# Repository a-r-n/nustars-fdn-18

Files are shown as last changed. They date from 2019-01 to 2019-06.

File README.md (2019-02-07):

# NUSTARS Foundation 2018/19
For remote telemetry and data processing.

## Avionics
Language(s): C++  
Board: Feather M0  
Sensors:  
- BNO055  
- BMP280  
- Adafruit Ultimate GPS  
- ADXL377
Radio: LoRa RFM95W @915MHz
Commercial Altimeters: Raven 4

An ADS is controlled by interpreting signals from the commercial altimeters. General telemetry information is read from custom avionics suite, and is packaged and sent to ground station (as well as being saved to flash). At some point TBD, data will be retransmitted from flash (in the likely event of loss during the flight).

## Ground display and processing
Language(s): Python  
Radio: Feather M0 w/ LoRa RFM95W

The ground station is responsible for interpreting and displaying both real-time and asynchronous data from the avionics package.
Further information TBD

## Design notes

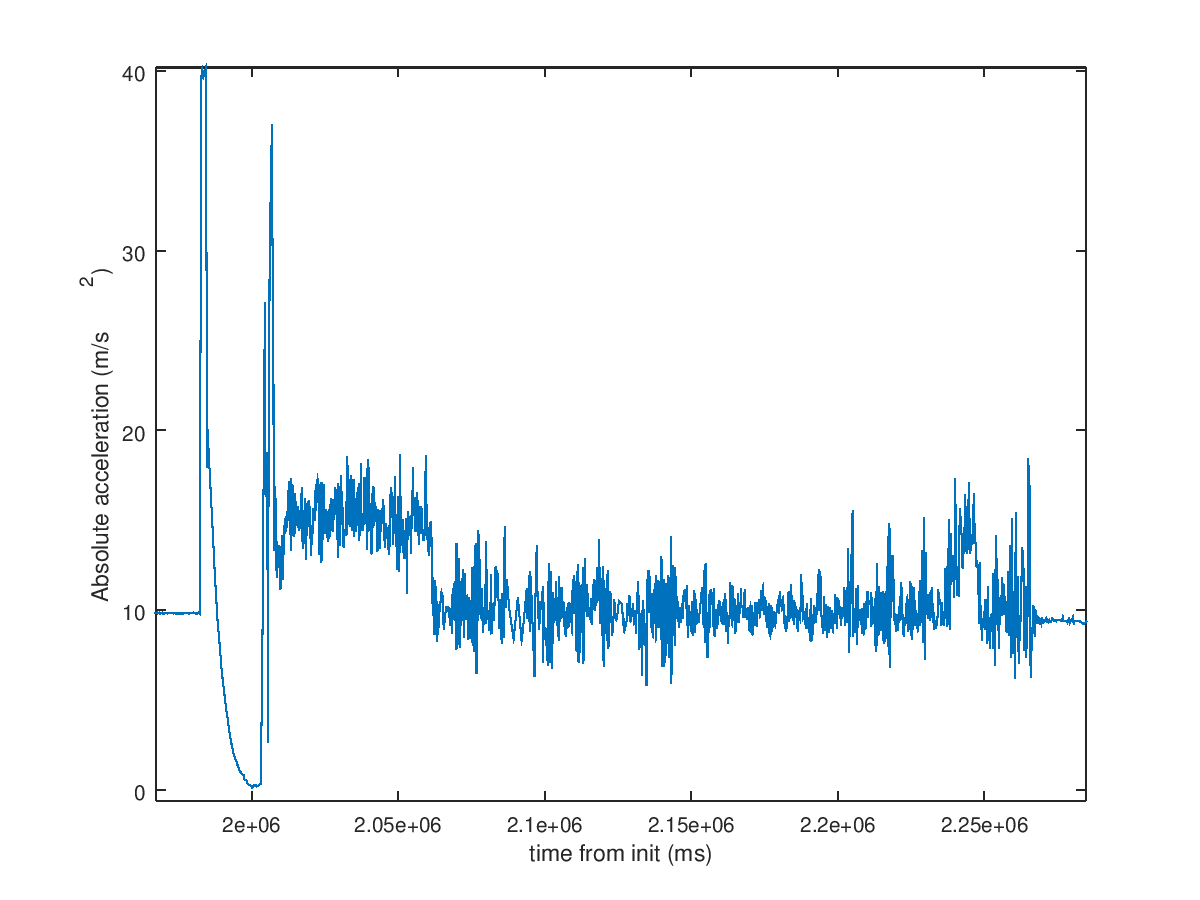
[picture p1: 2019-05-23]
matlab_parser/acc.png

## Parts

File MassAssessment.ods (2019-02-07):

Item | Mass (g) | Quantity | Subcost
M0 Exp | 4.7 | 1 | 4.7
LoRa | 4.6 | 1 | 4.6
GPS | 8.5 | 1 | 8.5
ADXL | 1.27 | 1 | 1.27
BNO | 3 | 1 | 3
BMP | 1.3 | 1 | 1.3
JST | 0.1 | 7 | 0.7
125x45 | 22.2 | 1 | 22.2
PerchRaven | 25 | 2 | 50
CylBats | 46 | 2 | 92
TOTAL |  |  | 188.27

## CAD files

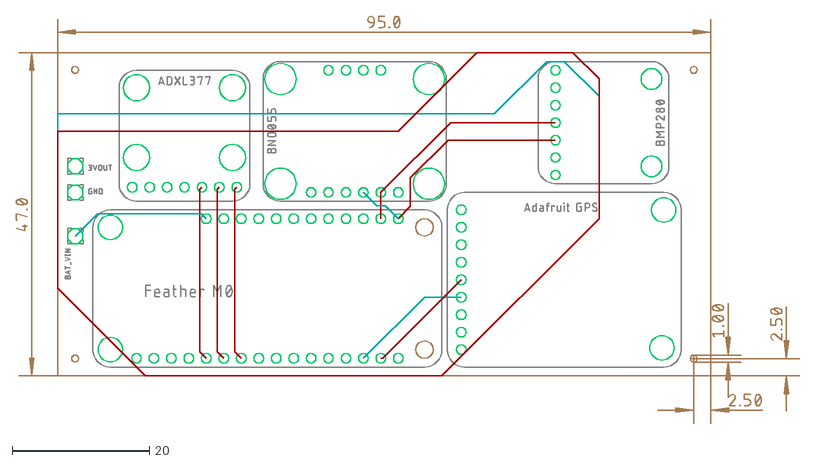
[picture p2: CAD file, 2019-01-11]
eagle/projects/NUSTARS18/Mainboard.dxf
114.0 x 59.2

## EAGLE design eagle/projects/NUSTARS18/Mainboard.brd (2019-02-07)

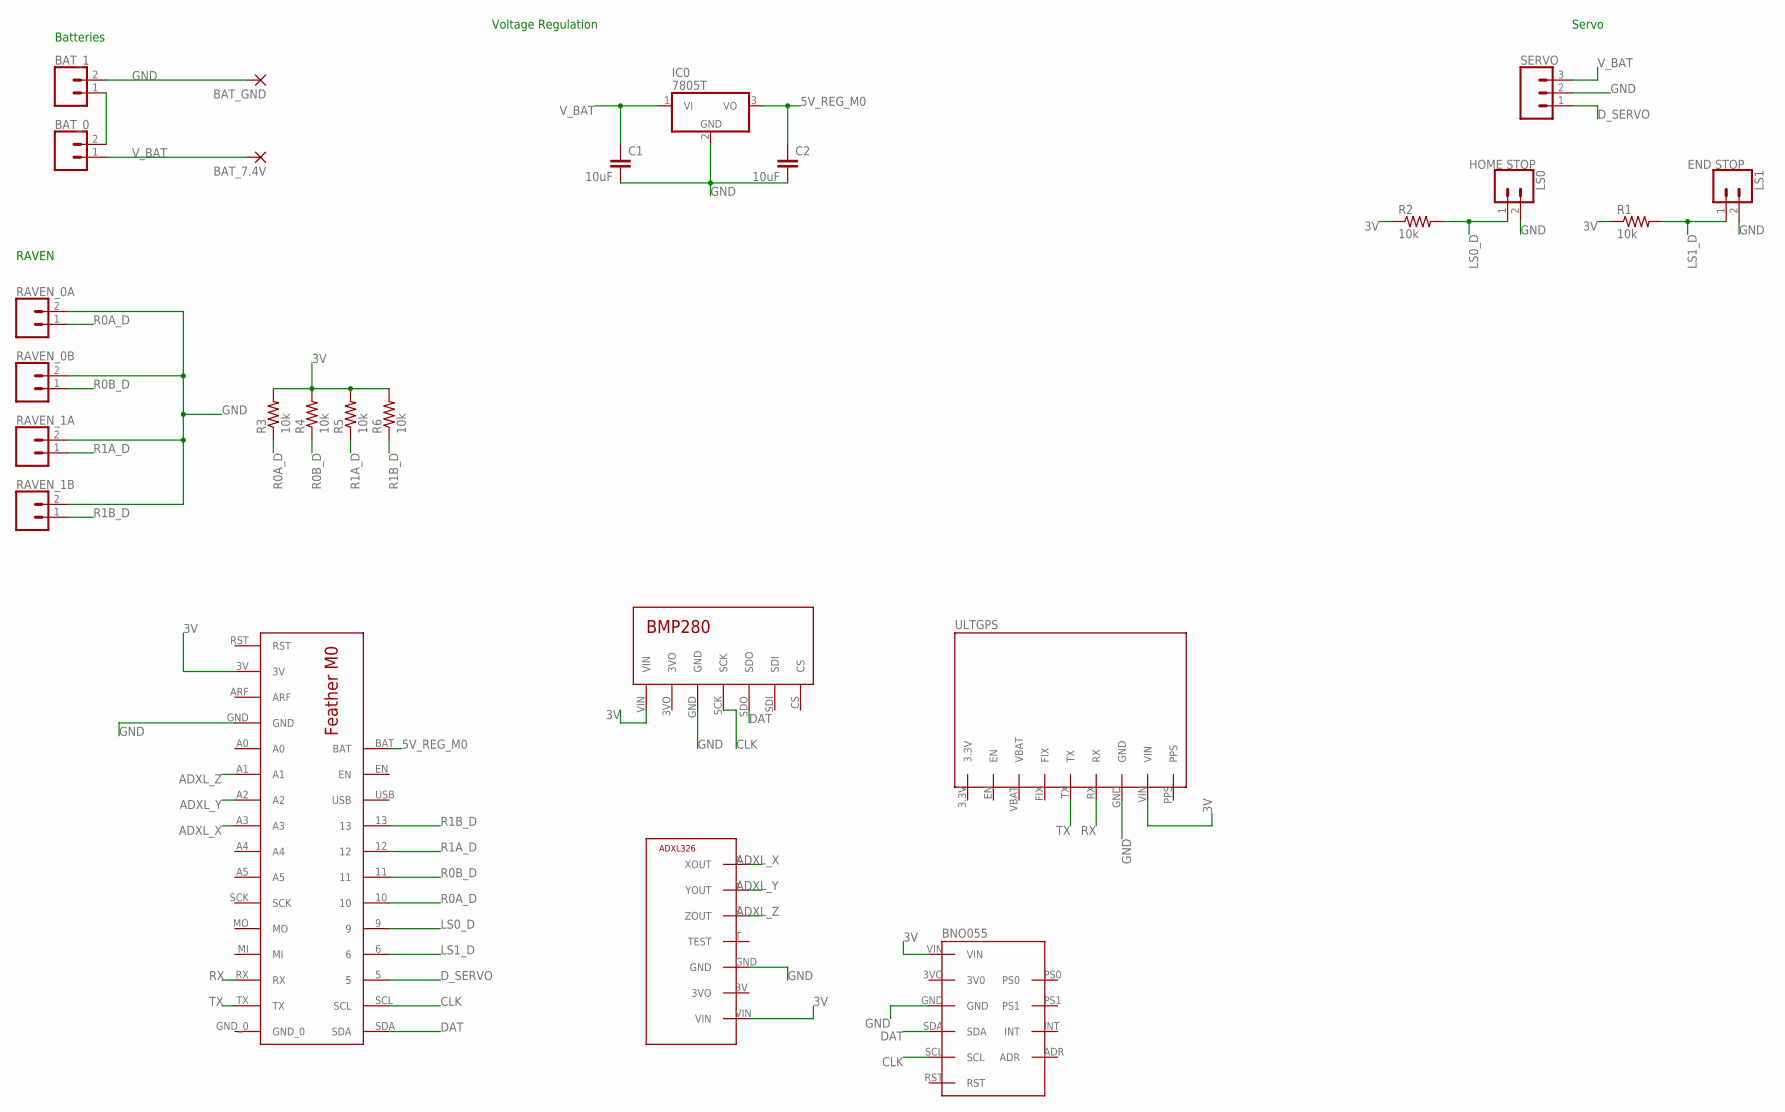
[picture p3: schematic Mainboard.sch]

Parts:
BAT_0, BAT_1: CONN_02JST-PTH-2; JST-2-PTH
BAT_7.4V: 3,81/1,4
BAT_GND: 3,81/1,4
C1, C2: 10uF; C2.5-3
IC0: 7805T; TO220H
LS0: HOME STOP; JST-2-PTH
LS1: END STOP; JST-2-PTH
R1, R2, R3, R4, R5, R6: 10k; 0207/10
RAVEN_0A, RAVEN_0B, RAVEN_1A, RAVEN_1B: CONN_02JST-PTH-2; JST-2-PTH
SERVO: CONN_03JST-PTH; JST-3-PTH
U$1: M0
U$2: BMP
U$3: ADXL377
U$4: ULTGPS
U$5: BNO055

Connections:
3V: R1.1, R2.1, R3.2, R4.2, R5.2, R6.2, U$1.3V, U$2.VIN, U$3.VIN, U$4.VIN, U$5.VIN
5V_REG_M0: C2.1, IC0.3 (VO), U$1.BAT
ADXL_X: U$1.A3, U$3.X (XOUT)
ADXL_Y: U$1.A2, U$3.Y (YOUT)
ADXL_Z: U$1.A1, U$3.Z (ZOUT)
B_INT: BAT_0.2, BAT_1.1
CLK: U$1.SCL, U$2.SCK, U$5.SCL
DAT: U$1.SDA, U$2.SDO, U$5.SDA
D_SERVO: SERVO.1, U$1.5
GND: BAT_1.2, BAT_GND.1, C1.2, C2.2, IC0.2 (GND), LS0.2, LS1.2, RAVEN_0A.2, RAVEN_0B.2, RAVEN_1A.2, RAVEN_1B.2, SERVO.2, U$1.GND, U$2.GND, U$3.GND, U$4.GND, U$5.GND
LS0_D: LS0.1, R2.2, U$1.9
LS1_D: LS1.1, R1.2, U$1.6
R0A_D: R3.1, RAVEN_0A.1, U$1.10
R0B_D: R4.1, RAVEN_0B.1, U$1.11
R1A_D: R5.1, RAVEN_1A.1, U$1.12
R1B_D: R6.1, RAVEN_1B.1, U$1.13
RX: U$1.RX, U$4.RX
TX: U$1.TX, U$4.TX
V_BAT: BAT_0.1, BAT_7.4V.1, C1.1, IC0.1 (VI), SERVO.3

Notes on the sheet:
Batteries
Voltage Regulation
Servo
RAVEN

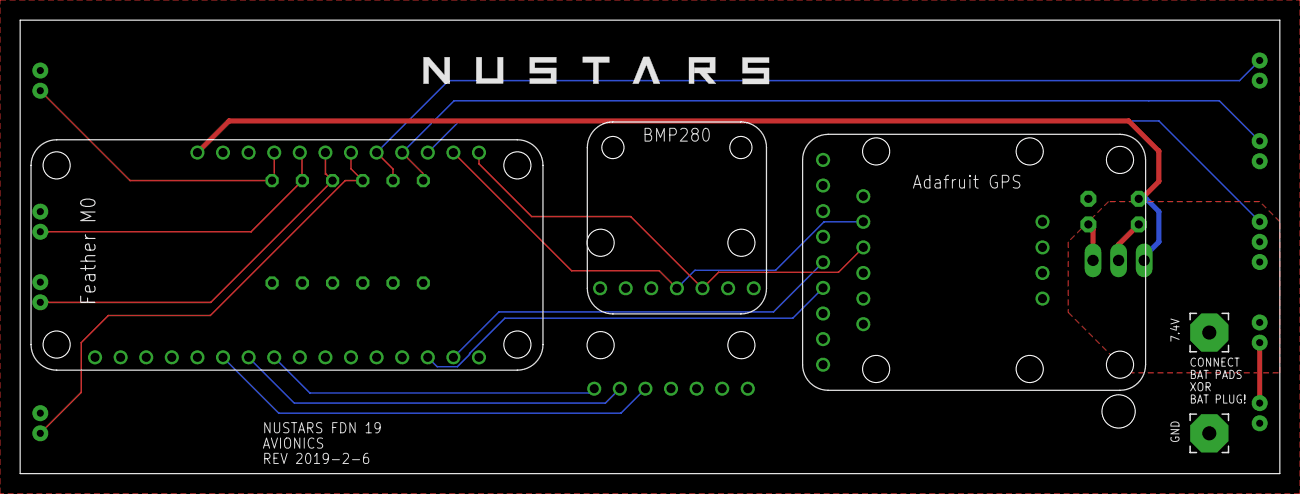
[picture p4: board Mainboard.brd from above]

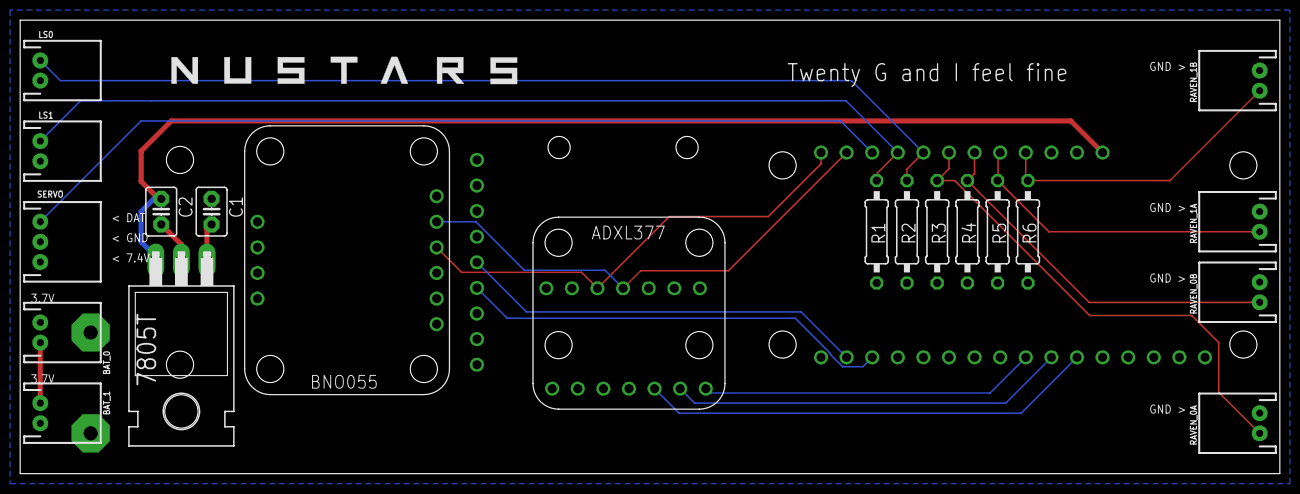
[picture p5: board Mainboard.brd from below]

Board: 2 copper layers, 125.0 x 45.0 mm, 25 parts (20 on the bottom side), 19 nets.

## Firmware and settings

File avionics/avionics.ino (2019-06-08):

#include "radio.h"
#include "sensors.h"
#include <Adafruit_NeoPixel.h>
#include <Adafruit_SPIFlash.h>
#include <Adafruit_SPIFlash_FatFs.h>
#include <SPI.h>
#include <Scheduler.h>
#include <Servo.h>
#include <Adafruit_GPS.h>
#include <Wire.h>

// FLASH DEFS TEMPORARY NO TIME

#define FLASH_TYPE                                                             \
  SPIFLASHTYPE_W25Q16BV // Flash chip type.
// If you change this be
// sure to change the fatfs
// object type below to match.

#if (SPI_INTERFACES_COUNT == 1)
#define FLASH_SS SS        // Flash chip SS pin.
#define FLASH_SPI_PORT SPI // What SPI port is Flash on?
#else
#define FLASH_SS SS1        // Flash chip SS pin.
#define FLASH_SPI_PORT SPI1 // What SPI port is Flash on?
#endif

// defining raven pins
#define R0A 10
#define R0B 11
#define R1A 12
#define R1B 13

// what's the name of the hardware serial port?
#define GPSSerial Serial1

// Connect to the GPS on the hardware port
Adafruit_GPS GPS(&GPSSerial);
#define GPSECHO false

#define PACKET_SIZE                                                            \
  70 // this is for optimization and ease of programming reasons... must be
// updated :(
#define WRITE_BUFFER_SIZE (2048 / PACKET_SIZE) * PACKET_SIZE

// setting debug stuff
#define DEBUG false
int divisor = 3;

// suspecting a race condition in the compiler or something else insane because
// this has to be moved sometimes for it to compile :O
union fusion_t {
  float f;
  int i;
  long l;
  uint8_t b[sizeof(long)];
};

// VERY TEMPORARY MEMORY CHECKING THING
#ifdef __arm__
// should use uinstd.h to define sbrk but Due causes a conflict
extern "C" char *sbrk(int incr);
#else  // __ARM__
extern char *__brkval;
#endif // __arm__

int freeMemory() {
  char top;
#ifdef __arm__
  return &top - reinterpret_cast<char *>(sbrk(0));
#elif defined(CORE_TEENSY) || (ARDUINO > 103 && ARDUINO != 151)
  return &top - __brkval;
#else  // __arm__
  return __brkval ? &top - __brkval : &top - __malloc_heap_start;
#endif // __arm__
}

// TEMPORARY
Adafruit_SPIFlash flash(FLASH_SS, &FLASH_SPI_PORT); // Use hardware SPI

// Alternatively you can define and use non-SPI pins!
// Adafruit_SPIFlash flash(FLASH_SCK, FLASH_MISO, FLASH_MOSI, FLASH_SS);

Adafruit_M0_Express_CircuitPython fatfs(flash);
// END TEMPORARY

// variables to store values for each pin
volatile int val0a = 0;
volatile int val0b = 0;
volatile int val1a = 0;
volatile int val1b = 0;

using namespace nustars;

Altimeter *alt;
IMU *imux;
ADXL *adxl;
Radio *radio;

Adafruit_NeoPixel led = Adafruit_NeoPixel(1, 8);

Servo servo;

uint8_t packetBuffer[PACKET_SIZE];
uint8_t writeBuffer[WRITE_BUFFER_SIZE]; // create the buffer of the size which
// is the max multiple of packet size
uint8_t writeBufferCopy[WRITE_BUFFER_SIZE]; // mind the stack frame limits,
// that's why this HAS to be global.
// Heap fragmentation not worth risk.
int wbPos =
  0; // henceforth this is now a RING BUFFER by royal decree on 2019-4-12
int bufferLocation; // for packetBuffer

char *tag = "NUx ";
int tagLength = 4;

uint8_t checksum; // the wireless checksum as byte

char *fn; // file name for the flash cell

// placing a variable here broke the union somehow, be cautious :(

fusion_t fusion;

volatile bool radioLock =
  false; // for communication between the main loop and radio signal loop
volatile bool writeSignal =
  false; // for communicaiton between the main loop and the write routine,
// this essentially makes it a non-blocking conditional execution

double base_acc;

int lastRaven = 0;

volatile int servoPos;

volatile bool deployed = false;

void setup() {
  if (DEBUG) {
    divisor = 4;
  }

  led.begin();
  setLED(255 / divisor, 0, 0); // RED: we are booting

  Serial.begin(115200);

  // wait for serial connection if we are in debug mode
  if (DEBUG) {
    while (!Serial)
      ;
  }
  Wire.begin();
  servo.attach(5);
  delay(1000);

  servoPos = 600;

  // TEMPORARY WRITING
  // Initialize flash library and check its chip ID.
  if (!flash.begin(FLASH_TYPE)) {
    Serial.println("Error, failed to initialize flash chip!");
    while (1)
      ;
  }
  Serial.print("Flash chip JEDEC ID: 0x");
  Serial.println(flash.GetJEDECID(), HEX);

  // First call begin to mount the filesystem.  Check that it returns true
  // to make sure the filesystem was mounted.
  if (!fatfs.begin()) {
    Serial.println("Error, failed to mount filesystem!");
    Serial.println(
      "Chip must be flashed with CircuitPython before use! Otherwise, this "
      "error may indicate a previous write panic.");
    while (1)
      ;
  }
  Serial.println("Mounted filesystem!");

  int dataID = 0;
  fn = (char *)calloc(20, 1);
  do {
    sprintf(fn, "data%d.hex\0", dataID);
    Serial.println("finding:");
    Serial.println(fn);
    dataID++;
  } while (fatfs.exists(fn));

  Adafruit_SPIFlash_FAT::File writeFile = fatfs.open(fn, FILE_WRITE);
  if (!writeFile) {
    Serial.println("Couldn't open the file!? WHyAsd?");
    while (1)
      ;
  }
  writeFile.close();
  Serial.print("found file that doesn't exist yet: ");
  Serial.println(fn);

  // END TEMPORARY

  // 9600 NMEA is the default baud rate for Adafruit MTK GPS's- some use 4800
  GPS.begin(9600);
  // uncomment this line to turn on RMC (recommended minimum) and GGA (fix data) including altitude
  GPS.sendCommand(PMTK_SET_NMEA_OUTPUT_RMCGGA);
  // uncomment this line to turn on only the "minimum recommended" data
  //GPS.sendCommand(PMTK_SET_NMEA_OUTPUT_RMCONLY);
  // For parsing data, we don't suggest using anything but either RMC only or RMC+GGA since
  // the parser doesn't care about other sentences at this time
  // Set the update rate
  GPS.sendCommand(PMTK_SET_NMEA_UPDATE_1HZ); // 1 Hz update rate
  // For the parsing code to work nicely and have time to sort thru the data, and
  // print it out we don't suggest using anything higher than 1 Hz
     
  // Request updates on antenna status, comment out to keep quiet
  GPS.sendCommand(PGCMD_ANTENNA);
  delay(500);
  
  // Ask for firmware version
  GPSSerial.println(PMTK_Q_RELEASE);
  Serial.println("Q: When");
  alt = new Altimeter();
  Serial.println("do");
  imux = new IMU();
  Serial.println("we");
  adxl = new ADXL(A1, A2, A3);
  Serial.println("all");
  radio = new Radio(A5, A4, A0);
  Serial.println("end?");

  Serial.println("A: Not today!");
  for (int i = 0; i < tagLength; i++) {
    packetBuffer[i] = tag[i];
  }

  // Raven detection pins
  pinMode(R0A, INPUT);
  pinMode(R0B, INPUT);
  pinMode(R1A, INPUT);
  pinMode(R1B, INPUT);

  setLED(120 / divisor, 120 / divisor, 0); // YELLOW: calibrate

  base_acc = 0;
  for (int i = 0; i < 20; i++) {
    imux->tick();
    ;
    base_acc +=
      sqrt(imux->getAcceleration(Y_AXIS) * imux->getAcceleration(Y_AXIS) +
           imux->getAcceleration(X_AXIS) * imux->getAcceleration(X_AXIS) +
           imux->getAcceleration(Z_AXIS) * imux->getAcceleration(Z_AXIS));
    delay(200);
  }

  base_acc /= 19;

  Serial.println(base_acc);

  for (int i = 30; i >= 25; i--) {
    servo.write(i);
    delay(20);
  }

  delay(1000);

  Scheduler.startLoop(writeFlash);
  Scheduler.startLoop(writeRadio);
  // Scheduler.startLoop(servoSend);

  Serial.println("finished setup");
  setLED(80 / divisor, 0, 120 / divisor); // PURPLE: everything okay
}

double moveTheAverage(double xn2, double xn1, double x0, double x1, double x2) {
  return (xn1 + x0 + x1 + (x2 + xn2) / 2) / 4;
}

double v = 0;
long lastdt = millis();

float maxAcc = 0;

void loop() {
  char c = GPS.read();
  // update the sensors
  if (GPS.newNMEAreceived()) {
    GPS.parse(GPS.lastNMEA());
  }
  alt->tick();
  imux->tick();
  adxl->tick();

  if (!radioLock) { // we are only interested in flashing data which is
    // also transmitted at these rates
    bufferLocation = tagLength; // offset for packet identifying prefix

    checksum = 0; // clear the checksum!

    // WARNING: No verification is being done to ensure data length. Keep it
    // under byte limit please package the current time
    fusion.l = millis();
    pack(fusion, packetBuffer, bufferLocation, sizeof(long));

    // package the data from the IMUx
    fusion.f = imux->getAcceleration(X_AXIS);
    pack(fusion, packetBuffer, bufferLocation, sizeof(float));
    fusion.f = imux->getAcceleration(Y_AXIS);
    pack(fusion, packetBuffer, bufferLocation, sizeof(float));
    fusion.f = imux->getAcceleration(Z_AXIS);
    pack(fusion, packetBuffer, bufferLocation, sizeof(float));

    // IMUx rotation

    fusion.f = imux->getOrientation(X_AXIS);
    pack(fusion, packetBuffer, bufferLocation, sizeof(float));
    fusion.f = imux->getOrientation(Y_AXIS);
    pack(fusion, packetBuffer, bufferLocation, sizeof(float));
    fusion.f = imux->getOrientation(Z_AXIS);
    pack(fusion, packetBuffer, bufferLocation, sizeof(float));

    // ADXL acceleration
    fusion.f = adxl->getAcceleration(X_AXIS);
    pack(fusion, packetBuffer, bufferLocation, sizeof(float));
    fusion.f = adxl->getAcceleration(Y_AXIS);
    pack(fusion, packetBuffer, bufferLocation, sizeof(float));
    fusion.f = adxl->getAcceleration(Z_AXIS);
    pack(fusion, packetBuffer, bufferLocation, sizeof(float));

    // BMP
    fusion.f = alt->getPressure();
    pack(fusion, packetBuffer, bufferLocation, sizeof(float));
    fusion.f = alt->getTemp();
    pack(fusion, packetBuffer, bufferLocation, sizeof(float));

    // MaxAcc
    // maxAcc = (imux->getAcceleration(Y_AXIS)) > maxAcc - (maxAcc < 0) * 2 *
    // maxAcc) ? imux->getAcceleration(Y_AXIS) : maxAcc;
    double yAcc = (adxl->getAcceleration(Y_AXIS));
    maxAcc = abs(yAcc) > abs(maxAcc) ? abs(yAcc) : maxAcc;

    // GPS
    fusion.f = GPS.latitude;
    Serial.println(GPS.latitude);
    Serial.println(GPS.longitude);
    pack(fusion, packetBuffer, bufferLocation, sizeof(float));
    fusion.f = GPS.longitude;
    pack(fusion, packetBuffer, bufferLocation, sizeof(float));
    fusion.f = GPS.altitude;
    pack(fusion, packetBuffer, bufferLocation, sizeof(float));
    fusion.f = (float)maxAcc;
    pack(fusion, packetBuffer, bufferLocation, sizeof(float));

    // Raven binary
    uint8_t raven = 0;
    val0a = digitalRead(R0A) == LOW;
    val0b = digitalRead(R0B) == LOW;
    val1a = digitalRead(R1A) == LOW;
    val1b = digitalRead(R1B) == LOW;

    raven |= val0a;
    raven |= val0b << 1;
    raven |= val1a << 2;
    raven |= val1b << 3;
    //Serial.println(raven);
    if (raven != lastRaven && !deployed) {
      //Serial.println(raven);
      if (val1b | val0b) {
        for (int i = 25; i < 75; i++) {
          servo.write(i);
          delay(20);
        }
        deployed = true;
      } else if (val1a | val0a) {
        for (int i = 25; i >= 75; i--) {
          servo.write(i);
          delay(20);
        }
        deployed = true;
      }
    } else {
      //Serial.println("LOL");
    }
    lastRaven = raven;

    fusion.b[0] = raven;
    pack(fusion, packetBuffer, bufferLocation, sizeof(uint8_t));

    // Finally, pack the checksum
    fusion.b[0] = checksum;
    uint8_t tmpsum = checksum; // note that this final pack call will reset the
    // checksum to 0 by nature of XOR...
    pack(fusion, packetBuffer, bufferLocation, sizeof(uint8_t));

    char msg[50];
    sprintf(msg, "Checksum: 0x%x\n\0", tmpsum);
    // Serial.write(msg);

    if (!writeSignal) // copy nothing if the thing is still waiting to do it!
      memcpy(writeBuffer + wbPos, packetBuffer, PACKET_SIZE);
    wbPos += PACKET_SIZE;
    if (WRITE_BUFFER_SIZE - wbPos <= PACKET_SIZE)
      writeSignal = true;
  }

  // maxAcc = (imux->getAcceleration(Y_AXIS)) > maxAcc - (maxAcc < 0) * 2 *
  // maxAcc) ? imux->getAcceleration(Y_AXIS) : maxAcc; yAcc =
  // (imux->getAcceleration(Y_AXIS)); maxAcc = abs(yAcc) > maxAcc ? abs(yAcc) :
  // maxAcc; Serial.println(maxAcc);
  // Serial.println(imux->getOrientation(X_AXIS));
  delay(5);
  yield(); // if you delete this the telemetry gods will kill you and your
  // family :(
}

// WARNING_TODO: this hasn't implemented the buffer duplication!
void writeFlash() {
  yield();
  if (writeSignal) {
    int cpyLen = wbPos + 1;
    memcpy(writeBufferCopy, writeBuffer, cpyLen);
    wbPos = 0;
    writeSignal = false;
    // long x = millis();
    Adafruit_SPIFlash_FAT::File writeFile = fatfs.open(fn, FILE_WRITE);
    if (!writeFile && DEBUG) {
      Serial.println("Error, failed to open file for writing!");
      while (1)
        ;
    } else if (writeFile) {
      writeFile.write(writeBufferCopy, cpyLen);
      writeFile.close();
    } else {
      setLED(255 / divisor, 255 / divisor, 0);
    }
    // Serial.println("--------------------------------WROTE");
    // //Serial.println(x - millis());
  }
  delay(10);
  yield();
}

/**
   Interesting note: the scheduler will not initiate this function until it has
   exited, so a stack overflow shouldn't be possible here. Therefore, we will
   let it just run aqap
*/
void writeRadio() {
  if (!radioLock) {
    //Serial.println("TRANSMIT!");
    radioLock = true; // signal the main loop not to update the packet buffer
    // while the radio is transmitting
    // consider making this a global (evil) so that it doesn't need to be
    // reallocated every time (possibly expensive!)
    uint8_t localBuffer[PACKET_SIZE]; // we create a local copy of the information
    // in case the main loop overwrites it during
    // scheduled time (conservative policy)
    long x = millis();
    memcpy(localBuffer, packetBuffer, PACKET_SIZE);
    radio->transmit(localBuffer, PACKET_SIZE);
    radioLock = false;
    //yield();
    delay(10);
    yield();
  }
}

volatile char sendlock = 0;

/**
   Packs fusion data into a buffer, incrementing index by size
   @param fuz fusion_t to pack
   @param buff buffer to place the data into
   @param index starting index of buff; incremented by size upon return
   @param size how many bytes of data to pack
*/
void pack(fusion_t fuz, uint8_t *buff, int &index, uint8_t size) {
  for (int i = 0; i < size; i++) {
    buff[index++] = fuz.b[i];
    checksum ^= fuz.b[i]; // XOR the checksum
  }
}

void setLED(uint8_t r, uint8_t g, uint8_t b) {
  led.setPixelColor(0, r / divisor, g / divisor, b / divisor);
  led.show();
}

/* //TODO: Implement this. Disabled to get things working for launch.
  void raven(){
    // read the pin
    val0a = digitalRead(r0a);
    val0b = digitalRead(r0b);
    val1a = digitalRead(r1a);
    val1b = digitalRead(r1b);
  }

*/

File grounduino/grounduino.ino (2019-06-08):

//NOTE: 255 bytes is the ABSOLUTE MAX packet size

#include <SPI.h>
#include <RH_RF95.h>

#define RFM95_CS 8
#define RFM95_RST 4
#define RFM95_INT 3
#define RF95_FREQ 915.0

#define DEBUG 1
#define PACKET_SIZE 70

RH_RF95 rf95(RFM95_CS, RFM95_INT);

uint8_t* recvBuf;
uint8_t* queue;
uint8_t head, tail;
int sz;

/**
 * Pushes bytes starting at x onto the queue
 */
uint8_t pushq(uint8_t* x, uint8_t len) {
  //abort if the queue cannot accomodate this new information
  
  if (255 - sz < (int)len) {
    return 0;
  }
  //copy the data here
  for (int i = 0; i < len; i++) {;
    queue[tail++] = x[i];
    sz++;
  }
  return 1;
}

/**
 * return the first byte in the queue
 * only call this after checking queue sz
 */
uint8_t popq() {
  uint8_t x = queue[head];
  head++;
  sz--;
  return x;
}

void setup() {
  head = 0;
  tail = 0;
  sz = 0;
  Serial.begin(115200);
  while (!Serial);
  recvBuf = (uint8_t*)malloc(256);
  queue = (uint8_t*)malloc(256); //abuse overflow for fast indexing by making it this size

  if (!recvBuf || !queue) {
    Serial.println("malloc failed!");
    while (1);
  }

  //BEGIN SETTING UP THE RADIO
  pinMode(RFM95_RST, OUTPUT);
  digitalWrite(RFM95_RST, HIGH);
  delay(10);
  digitalWrite(RFM95_RST, LOW);
  delay(10);
  digitalWrite(RFM95_RST, HIGH);
  delay(10);
  while (!Serial);
  while (!rf95.init()) {
    Serial.println("LoRa radio init failed");
    while (1);
  }

  if (!rf95.setFrequency(RF95_FREQ)) {
    Serial.println("setFrequency failed");
    while (1);
  }
  //Serial.println("Setup complete");
  rf95.setTxPower(23, false);
  //END SETTING UP THE RADIO
  
}

void loop() {
  digitalWrite(13, HIGH);
  while (!rf95.available());
  uint8_t len = 255;
  rf95.recv(recvBuf, &len);
  //Serial.write(recvBuf, PACKET_SIZE-5);
  pushq(recvBuf, len);

  uint8_t done = 0;
  if (sz >= 2*PACKET_SIZE) {
    while (!done || sz < PACKET_SIZE) {
      for (uint8_t x = 0; x != 'N'; x = popq());
      if (popq() == 'U' && popq() == 'x') {
        popq(); //kill the space part of flag
        done = 1;
      }
    }
    if (done) {
      uint8_t checksum = 0;//'N' ^ 'U' ^ 'x' ^ ' ';
      uint8_t buf[255];
      for (int i = 0; i < PACKET_SIZE-5; i++) {
        uint8_t x = popq();
        checksum ^= x;
        buf[i] = x;
      }
      if (checksum == popq()) {
        Serial.write("NUx ", 4);
        Serial.write(buf, PACKET_SIZE-5);
      } else {
        //Serial.write(buf, PACKET_SIZE-5);
      }
    }
    
  }
  /*
  if (queueReadPos + 3*PACKET_SIZE < queueReadPos) {
    Serial.println("Got A");
    uint8_t checksum = 0;
    while (queue[queueReadPos] != 'N' || queue[queueReadPos+1] != 'U' || queue[queueReadPos+2] != 'x')
      queueReadPos++;
    if (Serial.availableForWrite()) {
      Serial.write(queue+queueReadPos, PACKET_SIZE);
    }
  }
  */
  digitalWrite(13, LOW);
}

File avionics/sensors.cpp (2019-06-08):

#include "sensors.h"

namespace nustars {

    /**********IMU
     ***********************
     **********************/

    /**
     * Initialize the BNO
     */
    IMU::IMU() {
        bno = Adafruit_BNO055(); //I2C address, probably.
        orientation = new float[3];
        gyro = new float[3];
        acc = new float[3];
        if (!bno.begin()) {
            Serial.print(
                    "Ooops, no BNO055 detected ... Check your wiring or I2C ADDR!"); //TODO: Learn to throw an exception
            while (1);
        }
        bno.setExtCrystalUse(true);
        //Select page ID 1 to write to the right register
    }

    /**
     * Update the orientation information
     */
    void IMU::tick() {
        imu::Vector<3> euler = bno.getVector(Adafruit_BNO055::VECTOR_EULER);
        orientation[0] = euler.x();
        orientation[1] = euler.y();
        orientation[2] = euler.z();
        euler = bno.getVector(Adafruit_BNO055::VECTOR_GYROSCOPE);
        gyro[0] = euler.x();
        gyro[1] = euler.y();
        gyro[2] = euler.z();
        euler = bno.getVector(Adafruit_BNO055::VECTOR_ACCELEROMETER);
        acc[0] = euler.x();
        acc[1] = euler.y();
        acc[2] = euler.z();
    }

    /**
     * Reconnect the BNO if it is lost
     */
    void IMU::reconnect() {
        bno.begin();
    }

    /**
     * Get the current orientation
     * @param axis From Sensor class, integer representing axis to retrieve
     * @return The value of the orientation on requested axis
     */
    float IMU::getOrientation(int axis) {
        return orientation[axis];
    }

    float IMU::getGyro(int axis) {
        return gyro[axis];
    }

    /**
     * Get the current acceleration
     * @param axis From Sensor class, integer representing axis to retrieve
     * @return The value of the acceleration on requested axis
     */
    float IMU::getAcceleration(int axis) {
        return acc[axis];
    }


    /***********ADXL
     ********************
     *******************/
    ADXL::ADXL(int xPin, int yPin, int zPin) {
        this->xPin = xPin;
        this->yPin = yPin;
        this->zPin = zPin;
    }

    void ADXL::tick() {
        //unimplemented. We get the values just in time as they are one at a time anyway and we probably only want one
    }

    float ADXL::getAcceleration(int axis) {
        float rawData;
        switch (axis) {
            case X_AXIS:
                rawData = analogRead(xPin);
            case Y_AXIS:
                rawData = analogRead(yPin);
            case Z_AXIS:
                rawData = analogRead(zPin);
        }
        return (float)(rawData) * 400.0 / 1023.0 - 200; //this may not be completely accurate, but we are doing this to get mvp by the weekend
    }



    /***********ALTIMETER
     ********************
     *******************/

    /**
     * Initialize the BME and perform starting tasks
     */
    Altimeter::Altimeter() {
        if (!bme.begin(BMP_ADDR)) {
            Serial.println("Could not find a valid BMP280 sensor, check wiring!");
            while (1);
        }
        //bme.begin(0x76);
        setBaseAlt();
    }

    /**
     * Take several samples of the current altitude and record the average
     */
    void Altimeter::setBaseAlt() {
        const int NUM_BASE_SAMPLES = 10;
        //Set altitude at ground
        baseAlt = 0;
        for (int i = 0; i < NUM_BASE_SAMPLES; i++) {
            baseAlt += bme.readAltitude(1000);
        }
        baseAlt = baseAlt / NUM_BASE_SAMPLES; //average readings
    }

    /**
     * Update the current altitude, pressure, and temperature
     */
    void Altimeter::tick() {
        temp = bme.readTemperature();
        pressure = bme.readPressure();
        alt = bme.readAltitude(1000) - baseAlt;
    }

    //Altimeter getters

    //get temperature
    float Altimeter::getTemp() {
        return temp;
    }

    //get altitude
    float Altimeter::getAltitude() {
        return alt;
    }

    //get pressure
    float Altimeter::getPressure() {
        return pressure;
    }
} //END NAMESPACE

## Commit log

2018-11-01 Added external libs
    [project.cfg, serialconfig.txt]
2018-11-02 updated av<->ground code w/ experimental conclusion
2018-11-02 Added ground serial processor for interface with grounduino
2019-01-11 Added EAGLE files
    [Mainboard.brd, Mainboard.dxf, Mainboard.sch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]
2019-01-16 Updated board to latest requirements
    [Mainboard.brd, Mainboard.dxf, Mainboard.sch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]
2019-01-16 Updated board according to specs
2019-01-20 Updated the board yet again
    [Logo.brd, Mainboard.brd, Mainboard.dxf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]
2019-02-07 Added Raven JST to board
    [Mainboard.brd, Mainboard.sch]
2019-02-07 Added mass analysis and general board improvements
    [Mainboard.brd, Mainboard.sch, MassAssessment.ods]
2019-02-13 Oh boy some ground station programs
    These don't actually do much - but they're a proof of concept
2019-02-27 Set up servo shell, fixed LEDs
    The LEDs were too bright. Also I made code for l8r
    [avionics.ino, boardcode.ino]
2019-03-06 new ground station
2019-04-23 too much to record honestly, what a good commit note
    [avionics.ino]
2019-05-07 Add primitive servo code
2019-05-07 added checksum detection to grounduino, fixed BNO init
    [avionics.ino, grounduino.ino, sensors.cpp]
2019-05-19 Revert "LESS LIGHT"
    This reverts commit cfc7c2c2d01c2e73d02ea08bd9023cd5e27a22e1.
    [avionics.ino]
2019-06-08 Hopefully the last commit. Good year, all!
    [project.cfg, serialconfig.txt]

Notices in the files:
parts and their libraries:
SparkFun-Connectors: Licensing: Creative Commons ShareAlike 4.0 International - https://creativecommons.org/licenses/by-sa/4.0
